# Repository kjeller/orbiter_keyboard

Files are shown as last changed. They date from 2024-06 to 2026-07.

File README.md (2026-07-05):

# Orbiter Keyboard

A 52-key split keyboard.

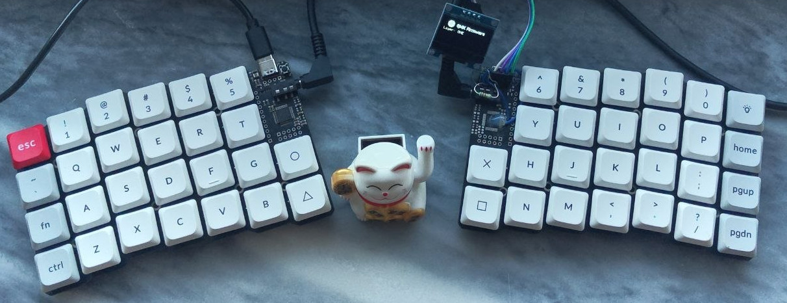
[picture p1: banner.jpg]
Split keyword showcase
 

!!DISCLAIMER!! There are issues with v1.00 that needs manual patching:
- BOOT0 logic is reversed which makes device always go into DFU mode, R6 needs to be connected to GND
- USB-C CC pin pull-up is common, which makes the USB cable one-way, CC1 and CC2 each needs a 5.1k pull-down resistor

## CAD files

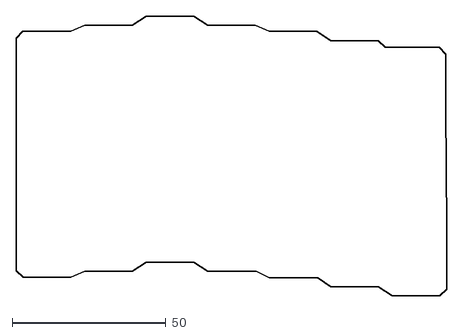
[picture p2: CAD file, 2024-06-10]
pcb/orbiter-wired/graphics/edge_cut_orbiter.dxf
140.0 x 91.0

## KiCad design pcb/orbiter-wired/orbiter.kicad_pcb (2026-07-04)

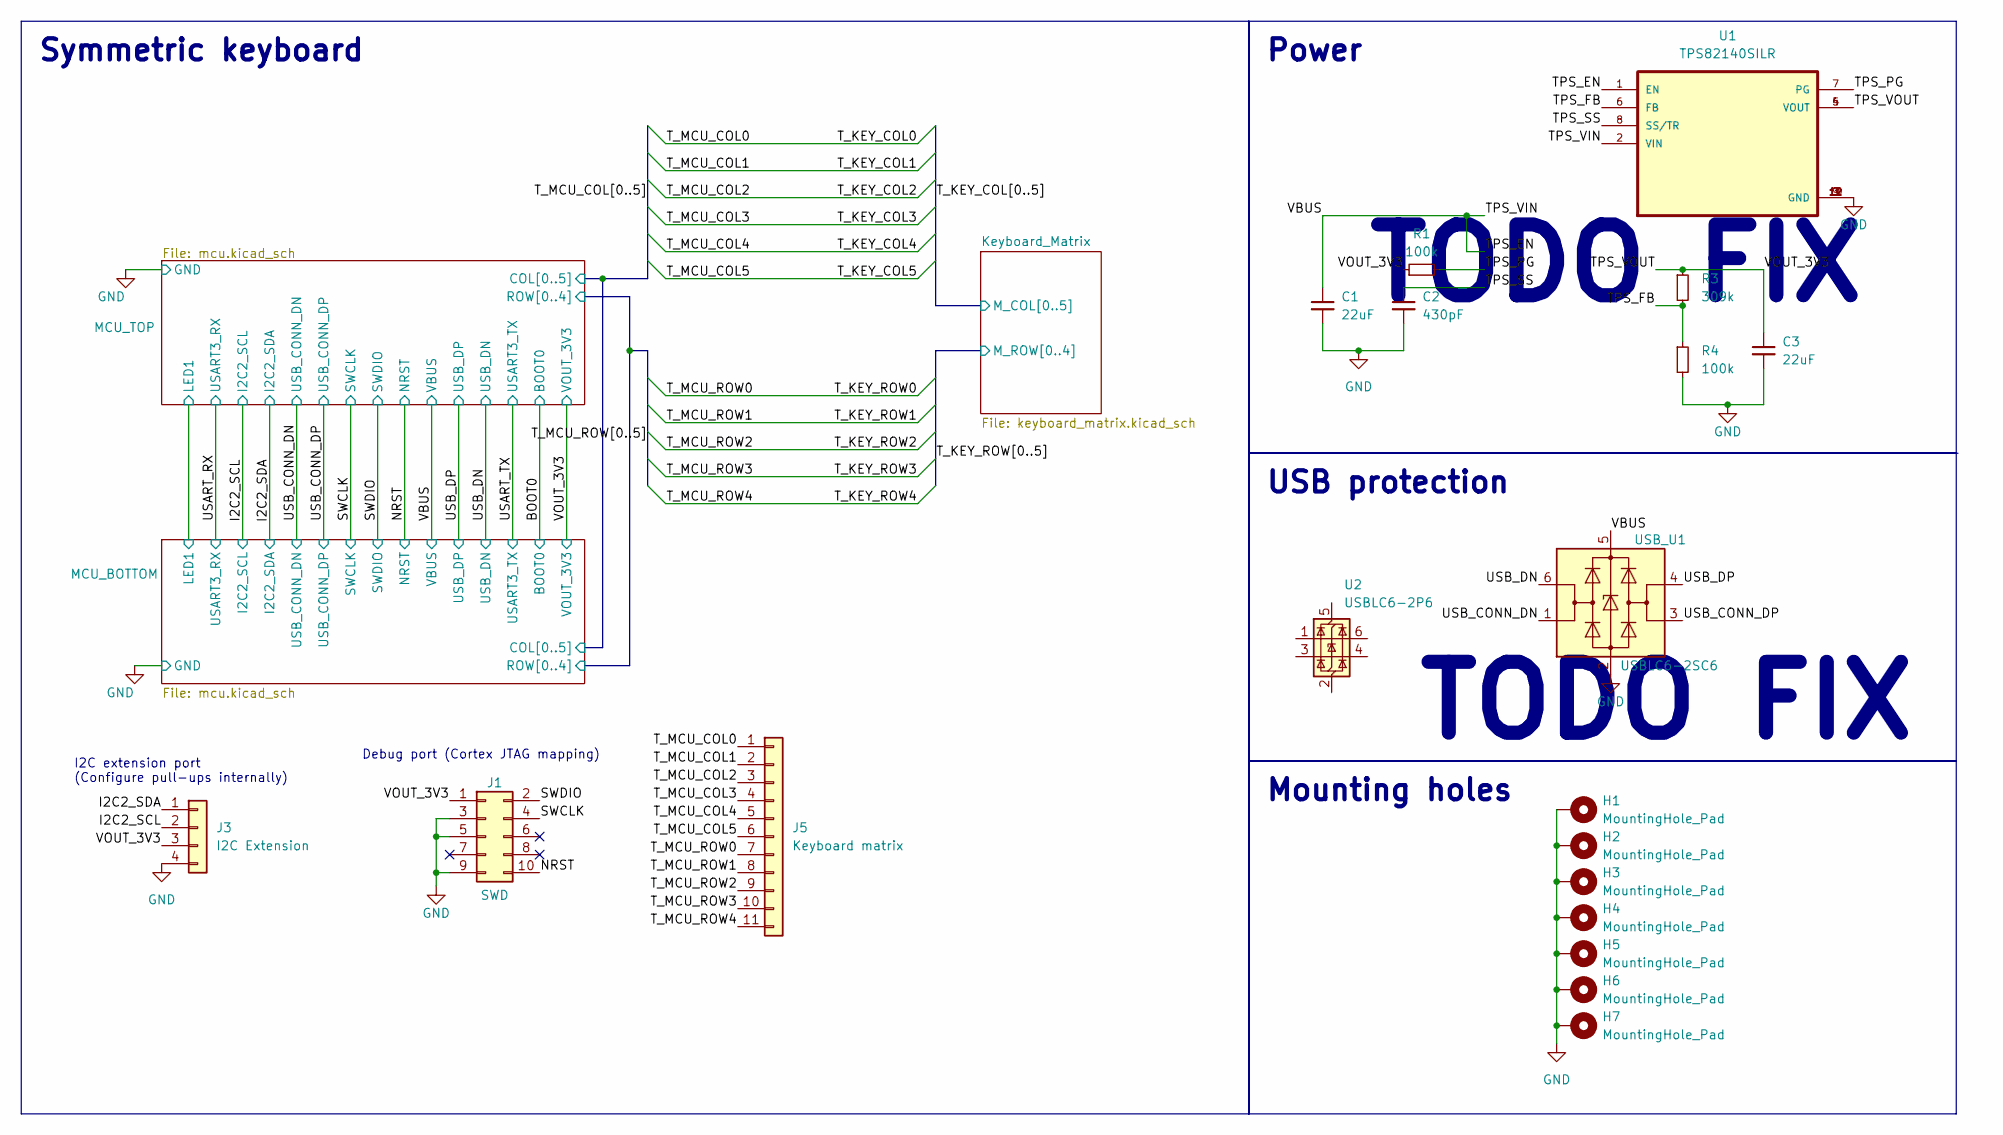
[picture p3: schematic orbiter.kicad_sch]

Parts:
C1, C3: 22uF; C_0603_1608Metric_Pad1.08x0.95mm_HandSolder; LCSC C59461
C2: 430pF; C_0603_1608Metric_Pad1.08x0.95mm_HandSolder; LCSC C1620
H1, H2, H3, H4, H5, H6, H7: MountingHole_Pad; MountingHole_2.7mm_M2.5_DIN965_Pad_reversible
J1: SWD; PinSocket_2x05_P2.54mm_Vertical
J3: I2C Extension; PinSocket_1x04_P2.54mm_Vertical
J5: Keyboard matrix; PinSocket_1x11_P2.54mm_Vertical
R1, R4: 100k; R_0603_1608Metric; LCSC C25803
R3: 309k; R_0603_1608Metric; LCSC C23024
U1: TPS82140SILR; LCSC C544385
U2: USBLC6-2P6; SOT-666
USB_U1: USBLC6-2SC6; SOT-23-6; LCSC C2687116

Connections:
/I2C2_SCL: J3.2; also elsewhere on the board
/I2C2_SDA: J3.1; also elsewhere on the board
/NRST: J1.10; also elsewhere on the board
/SWCLK: J1.4; also elsewhere on the board
/SWDIO: J1.2; also elsewhere on the board
/TPS_EN: C1.1, U1.1 (EN), U1.2 (VIN), USB_U1.5 (VBUS); also elsewhere on the board
/TPS_FB: R3.2, R4.1, U1.6 (FB)
/TPS_PG: R1.2, U1.7 (PG)
/TPS_SS: C2.1, U1.8 (SS/TR)
/TPS_VOUT: C3.1, J1.1, J3.3, R1.1, R3.1, U1.4 (VOUT), U1.5 (VOUT); also elsewhere on the board
/T_KEY_COL0: J5.1; also elsewhere on the board
/T_KEY_COL1: J5.2; also elsewhere on the board
/T_KEY_COL2: J5.3; also elsewhere on the board
/T_KEY_COL3: J5.4; also elsewhere on the board
/T_KEY_COL4: J5.5; also elsewhere on the board
/T_KEY_COL5: J5.6; also elsewhere on the board
/T_KEY_ROW0: J5.7; also elsewhere on the board
/T_KEY_ROW1: J5.8; also elsewhere on the board
/T_KEY_ROW2: J5.9; also elsewhere on the board
/T_KEY_ROW3: J5.10; also elsewhere on the board
/T_KEY_ROW4: J5.11; also elsewhere on the board
/USB_CONN_DN: USB_U1.1 (I/O1); also elsewhere on the board
/USB_CONN_DP: USB_U1.3 (I/O2); also elsewhere on the board
/USB_DN: USB_U1.6 (I/O1); also elsewhere on the board
/USB_DP: USB_U1.4 (I/O2); also elsewhere on the board
GND: C1.2, C2.2, C3.2, H1.1, H2.1, H3.1, H4.1, H5.1, H6.1, H7.1, J1.3, J1.5, J1.9, J3.4, R4.2, U1.3 (GND), U1.9 (GND), U1.10 (GND), U1.11 (GND), U1.12 (GND), USB_U1.2 (GND); also elsewhere on the board

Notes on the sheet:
TODO FIX
I2C extension port (Configure pull-ups internally)
Debug port (Cortex JTAG mapping)
Power
Symmetric keyboard
Mounting holes
USB protection

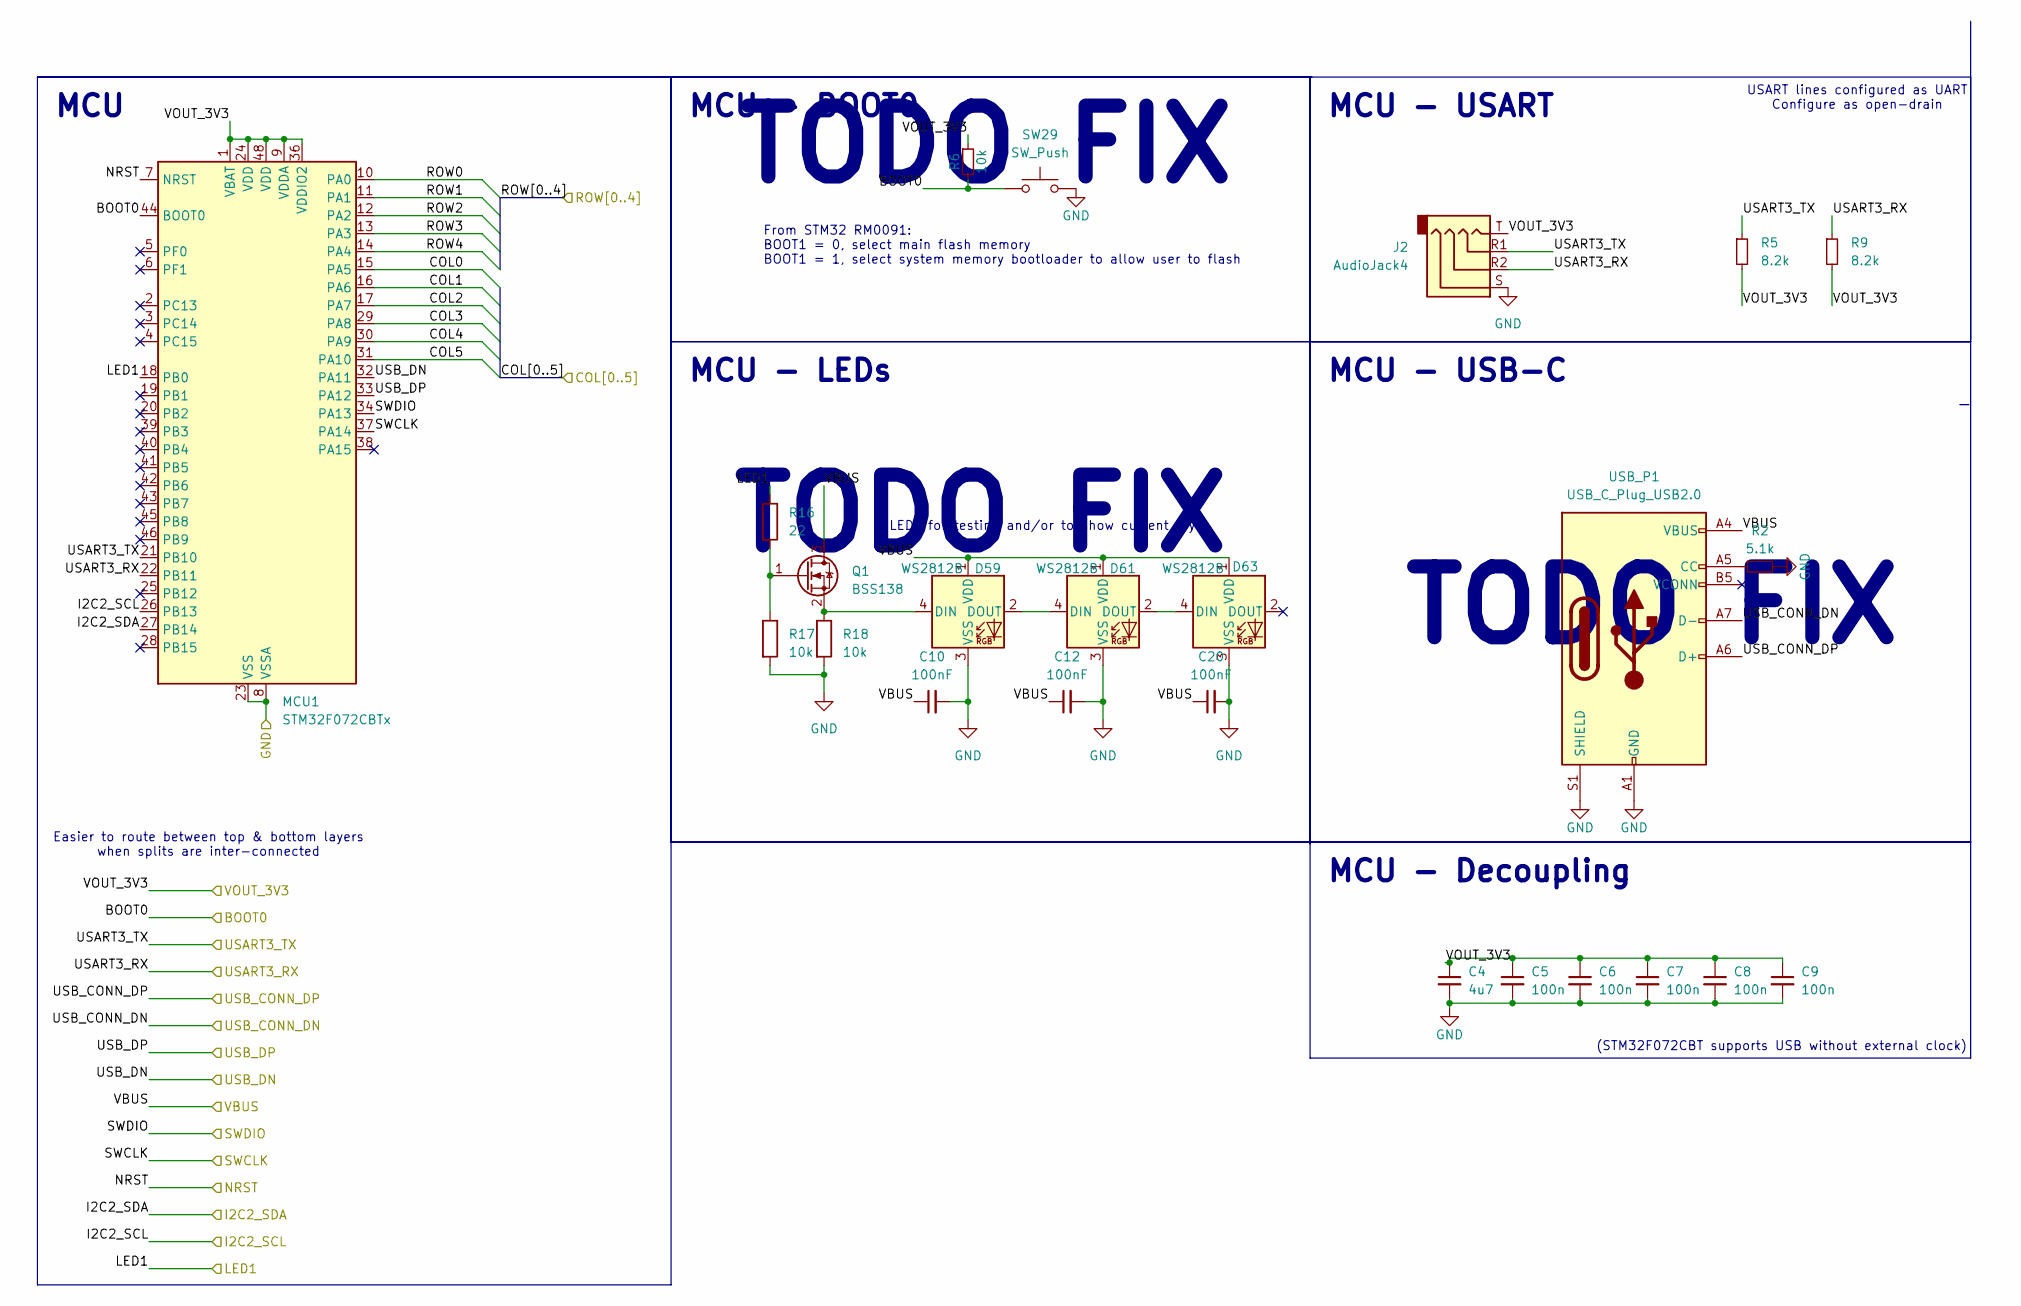
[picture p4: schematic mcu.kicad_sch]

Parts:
C4: 4u7; C_0603_1608Metric_Pad1.08x0.95mm_HandSolder
C5, C6, C7, C8, C9: 100n; C_0603_1608Metric_Pad1.08x0.95mm_HandSolder
C10, C12, C20: 100nF; C_0603_1608Metric_Pad1.08x0.95mm_HandSolder
D59, D61, D63: WS2812B; LED_WS2812B-2020_PLCC4_2.0x2.0mm
J2: AudioJack4; Jack_3.5mm_PJ320D_Horizontal
MCU1: STM32F072CBTx; LQFP-48_7x7mm_P0.5mm
Q1: BSS138; SOT-23; MPN BSS138
R2: 5.1k; R_0603_1608Metric
R5, R9: 8.2k; R_0603_1608Metric
R6, R17, R18: 10k; R_0603_1608Metric
R16: 22; R_0603_1608Metric
SW29: SW_Push; SW_SPST_PTS647_Sx38
USB_P1: USB_C_Plug_USB2.0; USB_C_Receptacle_XKB_U262-16XN-4BVC11

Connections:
/BOOT0: MCU1.44 (BOOT0), R6.2, SW29.1; also elsewhere on the board
/I2C2_SCL: MCU1.26 (PB13); also elsewhere on the board
/I2C2_SDA: MCU1.27 (PB14); also elsewhere on the board
/MCU_BOTTOM/LED1: MCU1.18 (PB0), R16.1; also elsewhere on the board
/NRST: MCU1.7 (NRST); also elsewhere on the board
/SWCLK: MCU1.37 (PA14); also elsewhere on the board
/SWDIO: MCU1.34 (PA13); also elsewhere on the board
/TPS_EN: C10.1, C12.1, C20.1, D59.1 (VDD), D61.1 (VDD), D63.1 (VDD), Q1.3 (D), USB_P1.A4 (VBUS), USB_P1.A9 (VBUS), USB_P1.B4 (VBUS), USB_P1.B9 (VBUS); also elsewhere on the board
/TPS_VOUT: C4.1, C5.1, C6.1, C7.1, C8.1, C9.1, J2.T, MCU1.1 (VBAT), MCU1.9 (VDDA), MCU1.24 (VDD), MCU1.36 (VDDIO2), MCU1.48 (VDD), R5.2, R6.1, R9.2; also elsewhere on the board
/T_KEY_COL0: MCU1.15 (PA5); also elsewhere on the board
/T_KEY_COL1: MCU1.16 (PA6); also elsewhere on the board
/T_KEY_COL2: MCU1.17 (PA7); also elsewhere on the board
/T_KEY_COL3: MCU1.29 (PA8); also elsewhere on the board
/T_KEY_COL4: MCU1.30 (PA9); also elsewhere on the board
/T_KEY_COL5: MCU1.31 (PA10); also elsewhere on the board
/T_KEY_ROW0: MCU1.10 (PA0); also elsewhere on the board
/T_KEY_ROW1: MCU1.11 (PA1); also elsewhere on the board
/T_KEY_ROW2: MCU1.12 (PA2); also elsewhere on the board
/T_KEY_ROW3: MCU1.13 (PA3); also elsewhere on the board
/T_KEY_ROW4: MCU1.14 (PA4); also elsewhere on the board
/USART_RX: J2.R2, MCU1.22 (PB11), R9.1; also elsewhere on the board
/USART_TX: J2.R1, MCU1.21 (PB10), R5.1; also elsewhere on the board
/USB_CONN_DN: USB_P1.A7 (D-); also elsewhere on the board
/USB_CONN_DP: USB_P1.A6 (D+); also elsewhere on the board
/USB_DN: MCU1.32 (PA11); also elsewhere on the board
/USB_DP: MCU1.33 (PA12); also elsewhere on the board
GND: C4.2, C5.2, C6.2, C7.2, C8.2, C9.2, C10.2, C12.2, C20.2, D59.3 (VSS), D61.3 (VSS), D63.3 (VSS), J2.S, MCU1.8 (VSSA), MCU1.23 (VSS), MCU1.35 (VSS), MCU1.47 (VSS), R2.2, R17.2, R18.2, SW29.2, USB_P1.A1 (GND), USB_P1.A12 (GND), USB_P1.B1 (GND), USB_P1.B12 (GND), USB_P1.S1 (SHIELD); also elsewhere on the board
unnamed: D59.4 (DIN), Q1.2 (S), R18.1
unnamed: D59.2 (DOUT), D61.4 (DIN)
unnamed: D61.2 (DOUT), D63.4 (DIN)
unnamed: Q1.1 (G), R16.2, R17.1
unnamed: R2.1, USB_P1.A5 (CC)

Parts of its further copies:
C11, C19, C21: 100nF; C_0603_1608Metric_Pad1.08x0.95mm_HandSolder
C13: 4u7; C_0603_1608Metric_Pad1.08x0.95mm_HandSolder
C14, C15, C16, C17, C18: 100n; C_0603_1608Metric_Pad1.08x0.95mm_HandSolder
D60, D62, D64: WS2812B; LED_WS2812B-2020_PLCC4_2.0x2.0mm
J4: AudioJack4; Jack_3.5mm_PJ320D_Horizontal
MCU2: STM32F072CBTx; LQFP-48_7x7mm_P0.5mm
Q2: BSS138; SOT-23; MPN BSS138
R7, R20, R21: 10k; R_0603_1608Metric
R8: 5.1k; R_0603_1608Metric
R10, R11: 8.2k; R_0603_1608Metric
R19: 22; R_0603_1608Metric
SW30: SW_Push; SW_SPST_PTS647_Sx38
USB_P2: USB_C_Plug_USB2.0; USB_C_Receptacle_XKB_U262-16XN-4BVC11

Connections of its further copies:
/BOOT0: MCU2.44 (BOOT0), R7.2, SW30.1; also elsewhere on the board
/I2C2_SCL: MCU2.26 (PB13); also elsewhere on the board
/I2C2_SDA: MCU2.27 (PB14); also elsewhere on the board
/MCU_BOTTOM/LED1: MCU2.18 (PB0), R19.1; also elsewhere on the board
/NRST: MCU2.7 (NRST); also elsewhere on the board
/SWCLK: MCU2.37 (PA14); also elsewhere on the board
/SWDIO: MCU2.34 (PA13); also elsewhere on the board
/TPS_EN: C11.1, C19.1, C21.1, D60.1 (VDD), D62.1 (VDD), D64.1 (VDD), Q2.3 (D), USB_P2.A4 (VBUS), USB_P2.A9 (VBUS), USB_P2.B4 (VBUS), USB_P2.B9 (VBUS); also elsewhere on the board
/TPS_VOUT: C13.1, C14.1, C15.1, C16.1, C17.1, C18.1, J4.T, MCU2.1 (VBAT), MCU2.9 (VDDA), MCU2.24 (VDD), MCU2.36 (VDDIO2), MCU2.48 (VDD), R7.1, R10.2, R11.2; also elsewhere on the board
/T_KEY_COL0: MCU2.15 (PA5); also elsewhere on the board
/T_KEY_COL1: MCU2.16 (PA6); also elsewhere on the board
/T_KEY_COL2: MCU2.17 (PA7); also elsewhere on the board
/T_KEY_COL3: MCU2.29 (PA8); also elsewhere on the board
/T_KEY_COL4: MCU2.30 (PA9); also elsewhere on the board
/T_KEY_COL5: MCU2.31 (PA10); also elsewhere on the board
/T_KEY_ROW0: MCU2.10 (PA0); also elsewhere on the board
/T_KEY_ROW1: MCU2.11 (PA1); also elsewhere on the board
/T_KEY_ROW2: MCU2.12 (PA2); also elsewhere on the board
/T_KEY_ROW3: MCU2.13 (PA3); also elsewhere on the board
/T_KEY_ROW4: MCU2.14 (PA4); also elsewhere on the board
/USART_RX: J4.R2, MCU2.22 (PB11), R10.1; also elsewhere on the board
/USART_TX: J4.R1, MCU2.21 (PB10), R11.1; also elsewhere on the board
/USB_CONN_DN: USB_P2.A7 (D-); also elsewhere on the board
/USB_CONN_DP: USB_P2.A6 (D+); also elsewhere on the board
/USB_DN: MCU2.32 (PA11); also elsewhere on the board
/USB_DP: MCU2.33 (PA12); also elsewhere on the board
GND: C11.2, C13.2, C14.2, C15.2, C16.2, C17.2, C18.2, C19.2, C21.2, D60.3 (VSS), D62.3 (VSS), D64.3 (VSS), J4.S, MCU2.8 (VSSA), MCU2.23 (VSS), MCU2.35 (VSS), MCU2.47 (VSS), R8.2, R20.2, R21.2, SW30.2, USB_P2.A1 (GND), USB_P2.A12 (GND), USB_P2.B1 (GND), USB_P2.B12 (GND), USB_P2.S1 (SHIELD); also elsewhere on the board
unnamed: D60.4 (DIN), Q2.2 (S), R21.1
unnamed: D60.2 (DOUT), D62.4 (DIN)
unnamed: D62.2 (DOUT), D64.4 (DIN)
unnamed: Q2.1 (G), R19.2, R20.1
unnamed: R8.1, USB_P2.A5 (CC)

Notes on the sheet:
TODO FIX
From STM32 RM0091: BOOT1 = 0, select main flash memory BOOT1 = 1, select system memory bootloader to allow user to flash
LEDs for testing and/or to show current layer
Easier to route between top & bottom layers when splits are inter-connected
USART lines configured as UART Configure as open-drain
(STM32F072CBT supports USB without external clock)
MCU - LEDs
MCU - USART
MCU - BOOT0
MCU - Decoupling
MCU
MCU - USB-C

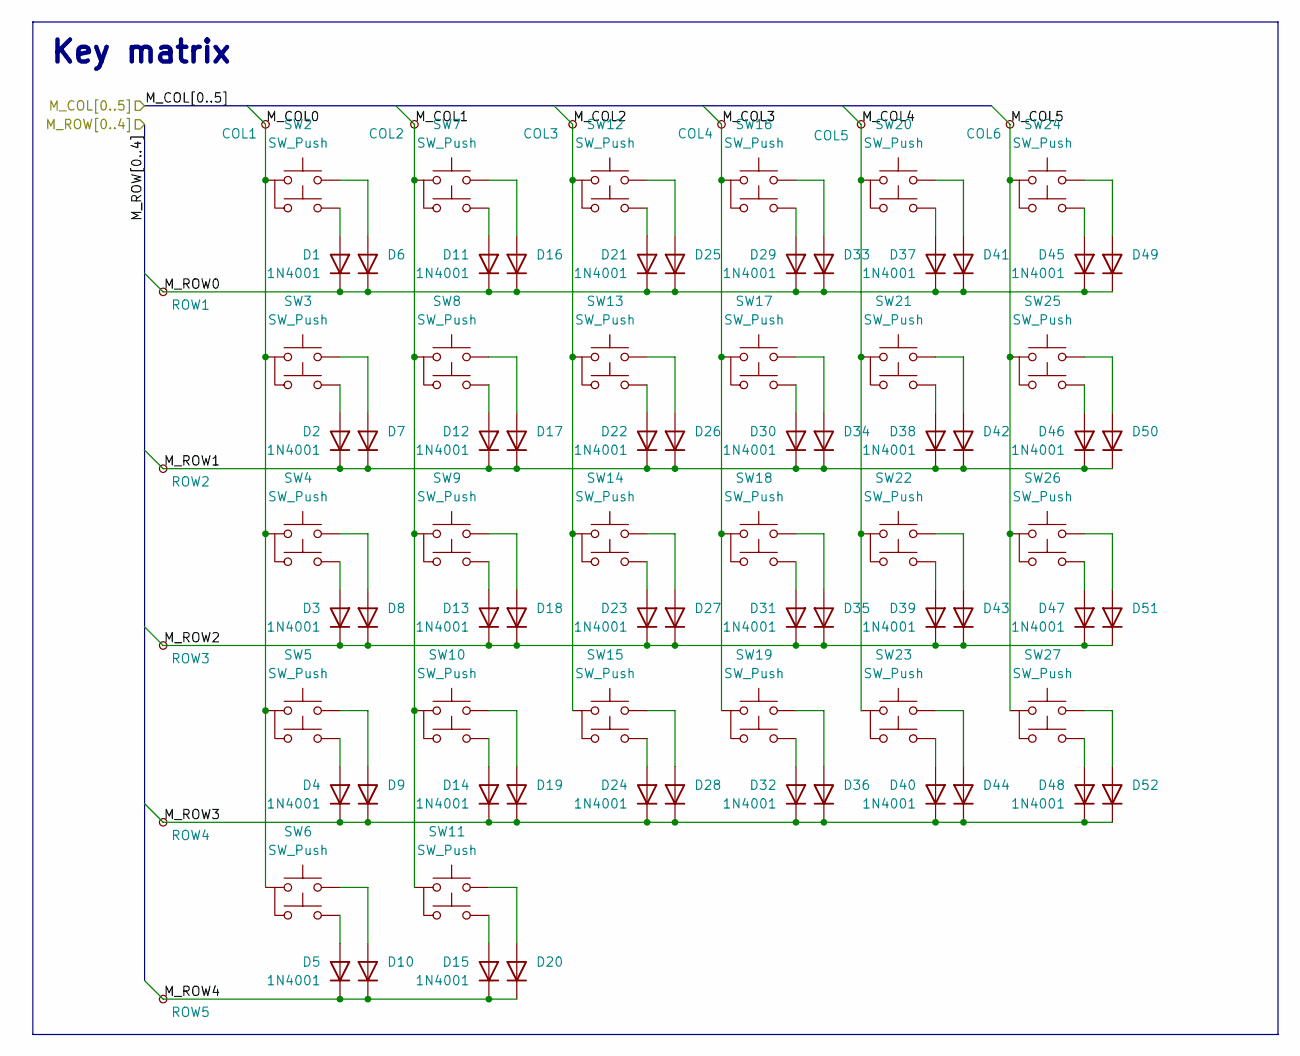
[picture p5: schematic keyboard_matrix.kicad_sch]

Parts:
COL1, COL2, COL3, COL4, COL5, COL6: TestPoint_Small; TestPoint_THTPad_D1.0mm_Drill0.5mm_reversible
D1, D2, D3, D4, D5, D6, D7, D8, D9, D10, D11, D12, D13, D14, D15, D16, D17, D18, D19, D20, D21, D22, D23, D24, D25, D26, D27, D28, D29, D30, D31, D32, D33, D34, D35, D36, D37, D38, D39, D40, D41, D42, D43, D44, D45, D46, D47, D48, D49, D50, D51, D52: 1N4001; D_SOD-323_HandSoldering
ROW1, ROW2, ROW3, ROW4, ROW5: TestPoint_Small; TestPoint_THTPad_D1.0mm_Drill0.5mm_reversible
SW2, SW3, SW4, SW5, SW6, SW7, SW8, SW9, SW10, SW11, SW12, SW13, SW14, SW15, SW16, SW17, SW18, SW19, SW20, SW21, SW22, SW23, SW24, SW25, SW26, SW27: SW_Push; SW_Kailh_Choc_V2_1.00u_Reversible

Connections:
/T_KEY_COL0: COL1.1, SW2.1, SW3.1, SW4.1, SW5.1, SW6.1; also elsewhere on the board
/T_KEY_COL1: COL2.1, SW7.1, SW8.1, SW9.1, SW10.1, SW11.1; also elsewhere on the board
/T_KEY_COL2: COL3.1, SW12.1, SW13.1, SW14.1, SW15.1; also elsewhere on the board
/T_KEY_COL3: COL4.1, SW16.1, SW17.1, SW18.1, SW19.1; also elsewhere on the board
/T_KEY_COL4: COL5.1, SW20.1, SW21.1, SW22.1, SW23.1; also elsewhere on the board
/T_KEY_COL5: COL6.1, SW24.1, SW25.1, SW26.1, SW27.1; also elsewhere on the board
/T_KEY_ROW0: D1.1 (K), D6.1 (K), D11.1 (K), D16.1 (K), D21.1 (K), D25.1 (K), D29.1 (K), D33.1 (K), D37.1 (K), D41.1 (K), D45.1 (K), D49.1 (K), ROW1.1; also elsewhere on the board
/T_KEY_ROW1: D2.1 (K), D7.1 (K), D12.1 (K), D17.1 (K), D22.1 (K), D26.1 (K), D30.1 (K), D34.1 (K), D38.1 (K), D42.1 (K), D46.1 (K), D50.1 (K), ROW2.1; also elsewhere on the board
/T_KEY_ROW2: D3.1 (K), D8.1 (K), D13.1 (K), D18.1 (K), D23.1 (K), D27.1 (K), D31.1 (K), D35.1 (K), D39.1 (K), D43.1 (K), D47.1 (K), D51.1 (K), ROW3.1; also elsewhere on the board
/T_KEY_ROW3: D4.1 (K), D9.1 (K), D14.1 (K), D19.1 (K), D24.1 (K), D28.1 (K), D32.1 (K), D36.1 (K), D40.1 (K), D44.1 (K), D48.1 (K), D52.1 (K), ROW4.1; also elsewhere on the board
/T_KEY_ROW4: D5.1 (K), D10.1 (K), D15.1 (K), D20.1 (K), ROW5.1; also elsewhere on the board
unnamed: D1.2 (A), SW2.3
unnamed: D2.2 (A), SW3.3
unnamed: D3.2 (A), SW4.3
unnamed: D4.2 (A), SW5.3
unnamed: D5.2 (A), SW6.3
unnamed: D6.2 (A), SW2.2
unnamed: D7.2 (A), SW3.2
unnamed: D8.2 (A), SW4.2
unnamed: D9.2 (A), SW5.2
unnamed: D10.2 (A), SW6.2
unnamed: D11.2 (A), SW7.3
unnamed: D12.2 (A), SW8.3
unnamed: D13.2 (A), SW9.3
unnamed: D14.2 (A), SW10.3
unnamed: D15.2 (A), SW11.3
unnamed: D16.2 (A), SW7.2
unnamed: D17.2 (A), SW8.2
unnamed: D18.2 (A), SW9.2
unnamed: D19.2 (A), SW10.2
unnamed: D20.2 (A), SW11.2
unnamed: D21.2 (A), SW12.3
unnamed: D22.2 (A), SW13.3
unnamed: D23.2 (A), SW14.3
unnamed: D24.2 (A), SW15.3
unnamed: D25.2 (A), SW12.2
unnamed: D26.2 (A), SW13.2
unnamed: D27.2 (A), SW14.2
unnamed: D28.2 (A), SW15.2
unnamed: D29.2 (A), SW16.3
unnamed: D30.2 (A), SW17.3
unnamed: D31.2 (A), SW18.3
unnamed: D32.2 (A), SW19.3
unnamed: D33.2 (A), SW16.2
unnamed: D34.2 (A), SW17.2
unnamed: D35.2 (A), SW18.2
unnamed: D36.2 (A), SW19.2
unnamed: D37.2 (A), SW20.3
unnamed: D38.2 (A), SW21.3
unnamed: D39.2 (A), SW22.3
unnamed: D40.2 (A), SW23.3
unnamed: D41.2 (A), SW20.2
unnamed: D42.2 (A), SW21.2
unnamed: D43.2 (A), SW22.2
unnamed: D44.2 (A), SW23.2
unnamed: D45.2 (A), SW24.3
unnamed: D46.2 (A), SW25.3
unnamed: D47.2 (A), SW26.3
unnamed: D48.2 (A), SW27.3
unnamed: D49.2 (A), SW24.2
unnamed: D50.2 (A), SW25.2
unnamed: D51.2 (A), SW26.2
unnamed: D52.2 (A), SW27.2

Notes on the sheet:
Key matrix

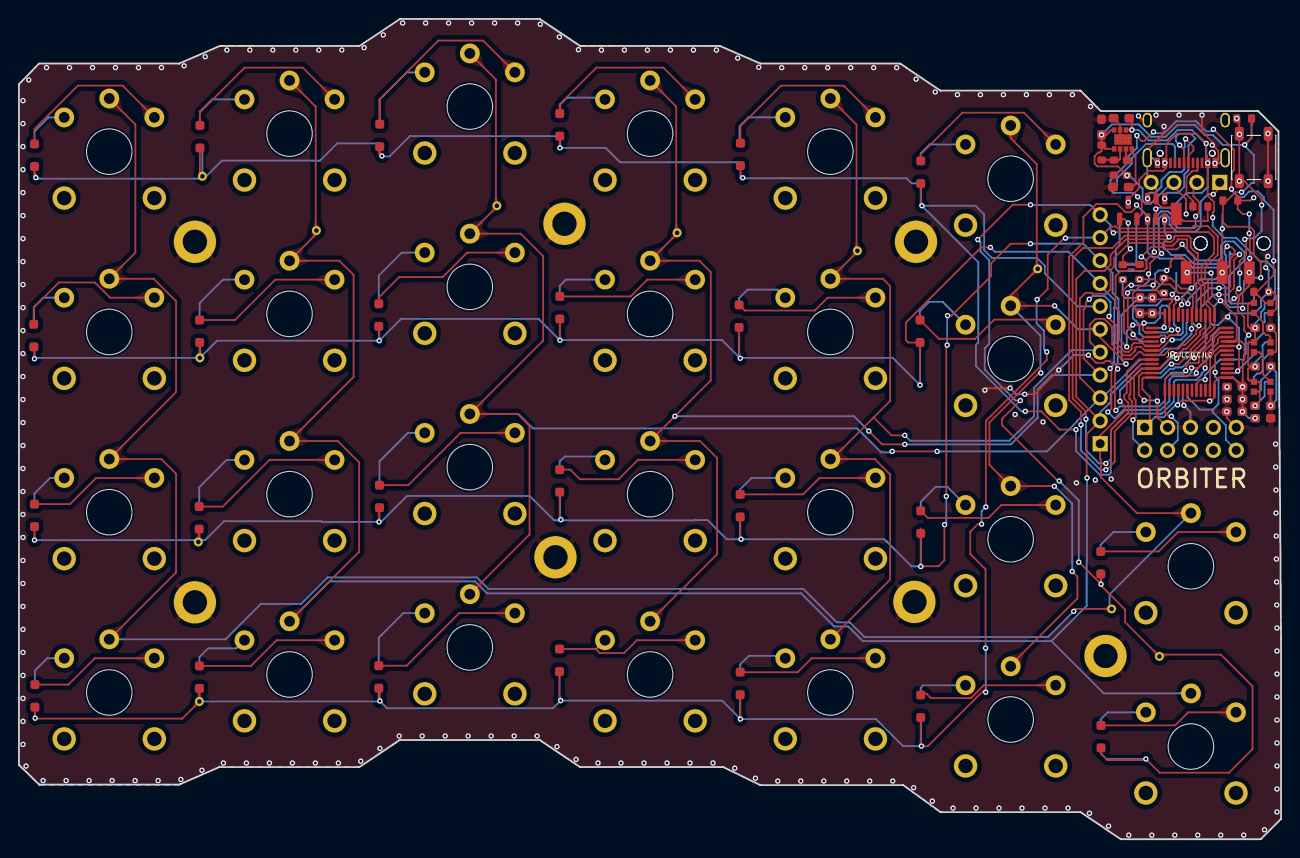
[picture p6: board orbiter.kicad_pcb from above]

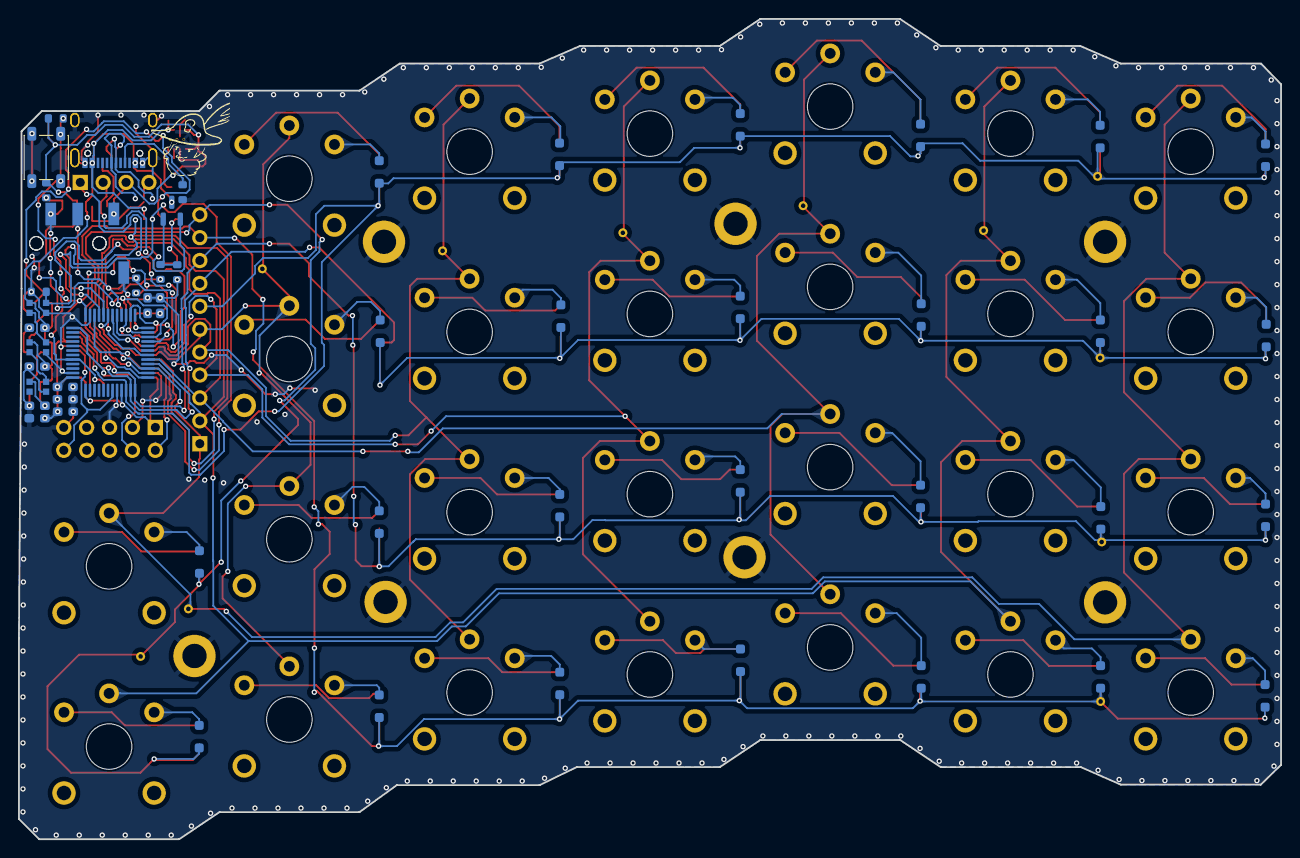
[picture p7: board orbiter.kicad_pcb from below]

Board: 2 copper layers, 140.0 x 91.0 mm, 155 parts (50 on the bottom side), 92 nets.

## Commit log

2024-05-07 Add BOOT0 handling and start working on power schematics
    [mcu.kicad_sch]
2024-05-08 Start adding USB C connector circuit
    [mcu.kicad_sch, supercrisp.kicad_pcb]
2024-05-10 Temp placement of switches and usb circuitry
    [mcu.kicad_sch, supercrisp.kicad_pcb, supercrisp.kicad_sch]
2024-05-10 Fix issue with sw push dual footprint
2024-05-10 Add step down circuit in schematic editor
    [mcu.kicad_sch, supercrisp.kicad_pcb]
2024-06-02 Add PCB fonts
2024-06-02 Continue placing components for USB
    [keyboard_matrix.kicad_sch, mcu.kicad_sch, supercrisp.kicad_pcb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]
2024-06-04 Fix flipped switch
    [supercrisp.kicad_pcb]
2024-06-04 Add pull down for USB CC
    [mcu.kicad_sch, supercrisp.kicad_pcb]
2024-06-04 Add colors to STEP Kailh switch
    [supercrisp.kicad_pcb]
2024-06-05 Add folder for step files
    Add PJ-320B step file
    [PJ-320D-A.STEP]
2024-06-05 Add TRRS connector for serial communication between splits
    [mcu.kicad_sch, supercrisp.kicad_pcb]
2024-06-06 Move step files to step folder
    Add step file for USB C jack
    [Kailh_PG1353.step, u262-161n-4bvc11.stp]
2024-06-06 Prel. placement of all components
    [supercrisp.kicad_pcb]
2024-06-06 Add step down step file
    [TPS82140SILR.STEP]
2024-06-06 WIP 0 errors, 58 warnings
    [keyboard_matrix.kicad_sch, mcu.kicad_sch, supercrisp.kicad_pcb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]
2024-06-06 Fix issue with duplicate edge cut
    [supercrisp.kicad_pcb]
2024-06-09 Cleanup routes and remove all silk
    [supercrisp.kicad_pcb]
2024-06-09 More cleanup
    [supercrisp.kicad_pcb]
2024-06-10 Add dxf file for edge cut
    [edge_cut_orbiter.dxf]
2024-06-10 GND copper fill zone now aligned with edge cut
    Move USB port closer to edge
    [supercrisp.kicad_pcb]
2024-06-10 Add via stitching around edge
    [supercrisp.kicad_pcb]
2024-06-10 Add JLPCB part numbers
    [keyboard_matrix.kicad_sch, mcu.kicad_sch, supercrisp.kicad_sch]
2024-06-10 Add JLCPCB hide text in silk
    [supercrisp.kicad_pcb]
2024-06-10 Replace temp project name with orbiter
    [Kailh_PG1353.step, PJ-320D-A.STEP, TPS82140SILR.STEP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]
2024-06-10 Adjust folder name slightly
    [Kailh_PG1353.step, PJ-320D-A.STEP, TPS82140SILR.STEP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]
2024-06-10 Add crude version text
    [orbiter.kicad_pcb]
2024-06-10 Use jlcpcb addon for db handling for BOM
2024-06-10 Latest schematic
    [mcu.kicad_sch, orbiter.kicad_pcb, orbiter.kicad_sch]
2024-06-10 Move diodes away from kb switch
    [orbiter.kicad_pcb]
2024-06-10 Orbiter wired v1.0 gerber & cleanup of old project files
    [esp_mcu_subsheet.kicad_sch, keyboard_matrix.kicad_sch, mcu.kicad_sch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]
2024-06-11 Change diode footprints 0603 -> SOD-323
    [keyboard_matrix.kicad_sch, mcu.kicad_sch, orbiter.kicad_pcb]
2024-06-11 Move symbols into their own folder
    Add footprint and symbol for TPS82140SILR that is correct size
    [orbiter.kicad_pcb, orbiter.kicad_sch]
2024-06-11 Put all diodes on respective side
    [orbiter.kicad_pcb]
2024-06-11 Add step file for TPS
    [orbiter.kicad_pcb]
2024-06-17 WIP prepare component placement for standalone dev pcb
    [WS2812B2020.STEP, mcu.kicad_sch, orbiter.kicad_pcb]
2024-06-23 Latest WIP
    [WS2812B2020.STEP, keyboard_matrix.kicad_sch, mcu.kicad_sch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]
2024-06-27 No DRC errors with new clean layout
    [mcu.kicad_sch, orbiter.kicad_pcb, orbiter.kicad_sch]
2024-06-27 Add pull-up for UART RX as well
    [mcu.kicad_sch, orbiter.kicad_pcb, orbiter.kicad_sch]
2024-06-27 Add via stitching and graphics on front silk back
    [orbiter.kicad_pcb]
2024-06-29 Edit project files to prepare for manufacturing
    [mcu.kicad_sch, orbiter.kicad_pcb]
2024-06-29 Set PCB version v1.00
    [orbiter.kicad_pcb]
2025-02-02 Add TODOs for fixes for next version
    [keyboard_matrix.kicad_sch, mcu.kicad_sch, orbiter.kicad_sch]
2025-02-02 Update paths to use kicad-library submodule
    [orbiter.kicad_pcb]
2025-02-02 Remove unused libraries from library migration
    [Kailh_PG1353.step, PJ-320D-A.STEP, TPS82140SILR.STEP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]
2026-07-04 Bump to Kicad 9
    [keyboard_matrix.kicad_sch, mcu.kicad_sch, orbiter.kicad_pcb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]
2026-07-04 fix schema inverted boot0 logic
    [mcu.kicad_sch]
2026-07-04 update schema to fix USB CC issue and add emc protection
    [mcu.kicad_sch]
